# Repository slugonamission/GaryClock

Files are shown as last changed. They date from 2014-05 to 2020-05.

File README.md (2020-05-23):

Time Containment and Dispersal Unit
=========
The structure of this repository is as follows:

* acrylic: Contains the Adobe Illustrator files for the plastic housing, and a template for the scales
* doc: Contains the (incomplete and abandoned) manual.
* libraries: Ignored
* notes: Misc stuff. Contains the programmer <-> clock I2C protocol.
* schematics: Contains the schematic for the power conditioning unit.
* src: Contains the actual clock source and tests.

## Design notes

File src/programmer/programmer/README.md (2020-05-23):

Building this programmer will require a little extra effort, since we're starting to hit the limits of what will actually fit on the Arduino.

Perform the following before attempting to build this project:

* Disable USB HID and CDC for the Arduino Leonardo. Go into Java/hardware/arduino/cores/arduino/USBDesc.h and comment out `#define CDC_ENABLED` and `#define HID_ENABLED`
* The SD card library needs replacing in order to use software SPI. Remove (or rename) Java/libraries/SD and instead use the AdaFruit version from https://learn.adafruit.com/adafruit-micro-sd-breakout-board-card-tutorial/library
* Since CDC is disabled, the Arduino can no longer be reset by the PC. Hit reset on the Arduino for the serial port to be detectable, and reset before attempting to program (the L LED should be pulsing in this period). The Arduino requires a power cycle to boot
        * Even with the HID and CDC libs, it needed power cycling anyway to detect the SD card again for some reason.

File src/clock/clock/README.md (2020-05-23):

Date/DS1307RTC modules taken from http://www.pjrc.com/teensy/td_libs_Time.html and http://www.pjrc.com/teensy/td_libs_DS1307RTC.html.

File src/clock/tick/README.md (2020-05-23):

Testing damping on the voltmeter, stopping some of the intertia from the heavy needle.

Damping is achieved by applying a reverse voltage (proportional to the distance) for a brief period of time after a specified delay from initial movement (the function in the file is fairly self-explanatory).
These values (in the file as #defines) can be tuned to improve the effect (may have to change them if we trim down the needle).

'tick.ino' contains the damped needle move function, as well as tests.

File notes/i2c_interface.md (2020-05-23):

Gary Clock I2C Semantics
==========================
+ The programmer will connect over I2C as a *slave* device.
    + The clock will already be an I2C master to communicate with the RTC.
+ The programmer will have slave ID `0x28`.
+ On connection, the clock must send a transaction to set the current time to the programmer. The programmer *probably* will not start unless this is sent.
+ The transaction format is `<regnum><data1><data2>...<datan>`. Writes to different registers **must** be contained in seperate transactions. Transaction splitting is not supported.
+ The register file is as follows:

        RegNum         Dir          Data
        0              R/W          The current time of the format <hour><min><second>, all as seperate 8 bit words.
        1              R/W          The current LED state.

+ Current I2C layout map:

        Addr          Usage
        0x28          Programmer
        0x68          RTC (DS1338)
        0x70 - 0x72   7-seg displays

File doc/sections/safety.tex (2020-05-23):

%!TEX root=../manual.tex

\begin{figure}[h!]
\centering
To avoid injury, read all operating instructions and the following safety information before using your \touchmore{}. For detailed operating instructions, read this User Guide carefully.
\caption{Important Information Warning 1}
\end{figure}

\begin{figure}[h!]
\centering
Failure to follow these safety instructions could result in fire, electric shock, or other injury or damage to the \touchmore{} or other property.
\caption{Important Information Warning 2}
\end{figure}

\begin{figure}[h!]
\centering
Do not open the \touchmore{} power conditioning unit. This device contains an anti-tamper mechanism which will be triggered by attempting to open the unit. The partners take no responsibility for any damage to persons, property or pride by by attmpting to open this unit.
\caption{Important Information Warning 3}
\end{figure}

\begin{figure}[h!]
\centering
DO NOT CONNECT THE \touchmore{} POWER CONDITIONING UNIT TO MAINS. CONNECTING THE \touchmore{} POWER CONDITIONING UNIT TO MAINS MAY LEAD TO INJURY OR DEATH FOR THE OPERATOR, OR DAMAGE TO ANY CONNECTED COMPONENTS.
\caption{Actual Important Information Warning 1}
\end{figure}

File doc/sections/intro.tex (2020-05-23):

%!TEX root=../manual.tex

Congratulations on the purchase of your new \touchmore{}. If suitably cared for, your \touchmore{} will provide you with years of time viewing pleasure, upon years of time storage.

We here at the Real Time group have used our years of experience in manufacturing, programming, and time viewing in order to create a fantastic timepiece, utilising the most cutting edge research in time viewing, time setting and power conditioning in order to provide you with the best experience possible in the coming \st{millennia} \st{centuries} \st{decades} \st{years} \st{months} days of time viewing that your brand new timepiece is designed for. As the result of the cumilation of three years and two extensions of real-time research, tentatively funded by EU grant number FP7-ICT-2011-7, we are sure that your new timepiece will bring you many minutes of joy.

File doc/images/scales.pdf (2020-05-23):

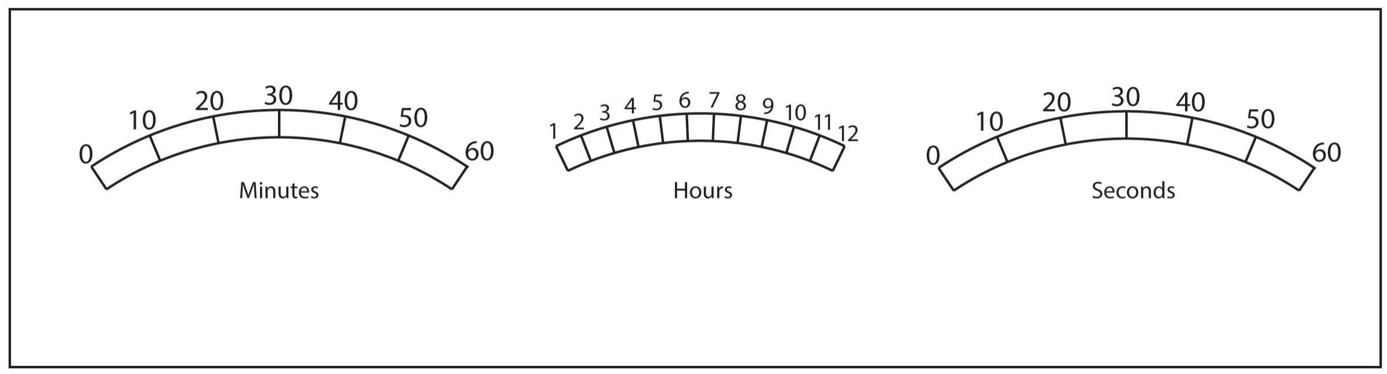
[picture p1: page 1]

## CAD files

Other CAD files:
acrylic/design-landscape.dwg

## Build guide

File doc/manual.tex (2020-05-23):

\documentclass[11pt,a4paper,twoside,titlepage]{scrartcl}

\usepackage[%
  includeheadfoot,
  headheight=44pt,
  headsep=60pt,
  hmargin=2cm,
  top=1cm,
  bottom=1.4cm
]{geometry}
\usepackage[pagestyles,raggedright]{titlesec}
\usepackage{lastpage,multirow,tabularx}
\usepackage{graphicx}
\usepackage{appendix}
\usepackage{lipsum}
\usepackage[pdfusetitle,hidelinks]{hyperref}
\usepackage{listings}
\usepackage{hyperref}
\usepackage{todonotes}
\usepackage{xcolor}
\usepackage{soul}

\usepackage{float}
\restylefloat{table}

\usepackage{datetime}
\ddmmyyyydate

\interfootnotelinepenalty=9999

\lstset{ %
basicstyle=\footnotesize,       % the size of the fonts that are used for the code
numbers=left,                   % where to put the line-numbers
numberstyle=\footnotesize,      % the size of the fonts that are used for the line-numbers
stepnumber=1,                   % the step between two line-numbers. If it's 1 each line will be numbered
numbersep=5pt,                  % how far the line-numbers are from the code
showspaces=false,               % show spaces adding particular underscores
showstringspaces=false,         % underline spaces within strings
showtabs=false,                 % show tabs within strings adding particular underscores
frame=single,                   % adds a frame around the code (tb for top bottom)
tabsize=4,                      % sets default tabsize to 2 spaces
captionpos=b,                   % sets the caption-position to bottom
breaklines=true,                % sets automatic line breaking
breakatwhitespace=false,        % sets if automatic breaks should only happen at whitespace
escapeinside={\%*}{*)}          % if you want to add a comment within your code
}

\title{\vspace{-24pt}\Huge Multi-Function Analogue Clock}
\subtitle{\vspace{8pt}\LARGE User Manual}
\author{}
\date{\vspace{12pt}}

\renewcommand{\tablename}{\textbf{Tip}}
\renewcommand{\figurename}{\textbf{Warning}}
\newcommand{\touchmore}{\textcolor{blue}{ToucHMore Time Storage and Dispersal Unit}}

\newcommand{\clock}{MULTI-FUNCTION~ANALOGUE~CLOCK}

\makeatletter
\let\Title\@title
\let\Author\@author
\let\Date\@date
\makeatother

% Page setup (titlesec)
\newpagestyle{manual}{%
%  \widenhead[1cm][1cm][1cm][1cm]
  \widenhead*{1cm}{1cm}
  \sethead[][\begin{tabularx}{\linewidth}{|>{\centering}p{4cm}|>{\centering}X|p{4cm}|}\hline
               & & \multirow{6}{*}{} \\
               User Manual & \textbf{\MakeUppercase{MULTI-FUNCTION ANALOGUE CLOCK}} & \\
               & & \\ \cline{1-2}
               & & \\
               Page \thepage\ of \pageref{LastPage} & Department of Computer Science, University of York & \\
               & & \\ \hline
             \end{tabularx}][]
          {}{\begin{tabularx}{\linewidth}{|p{4cm}|>{\centering}X|>{\centering\arraybackslash}p{4cm}|}\hline
               \multirow{6}{*}{} & & \\
               & \textbf{\MakeUppercase{MULTI-FUNCTION ANALOGUE CLOCK}} & User Manual \\
               & & \\ \cline{2-3}
               & & \\
               & Department of Computer Science, University of York & Page \thepage\ of \pageref{LastPage} \\
               & & \\ \hline
             \end{tabularx}}{}
  \setfoot[][\begin{tabularx}{\linewidth}{|p{3cm}|p{3cm}|X|}\hline
               Edition: 1 & Revision: A & \multirow{2}{*}{Approved: \textit{RJ, MF, IG, GL, JG}} \\
               Date: \today & Date: \today & \\\hline
             \end{tabularx}][]
          {}{\begin{tabularx}{\linewidth}{|p{3cm}|p{3cm}|X|}\hline
               Edition: 1 & Revision: A & \multirow{2}{*}{Approved: \textit{RJ, MF, IG, GL, JG}} \\
               Date: \today & Date: \today & \\\hline
             \end{tabularx}}{}
}
\pagestyle{manual}

\begin{document}

\maketitle

\section{Introduction}
\input{sections/intro.tex}

\clearpage
\section{Important Safety Information}
\input{sections/safety.tex}

\clearpage
\section{Basic Operation}
\input{sections/basic.tex}

\clearpage
\section{Advanced Functionality}
\input{sections/advanced.tex}

\clearpage
\appendix
\appendixpage

\input{sections/appendices.tex}

\clearpage
\section{Notes}
\vspace{1cm}
\noindent\rule{\textwidth}{0.2pt}
\vspace{1cm}
\noindent\rule{\textwidth}{0.2pt}
\vspace{1cm}
\noindent\rule{\textwidth}{0.2pt}
\vspace{1cm}
\noindent\rule{\textwidth}{0.2pt}
\vspace{1cm}
\noindent\rule{\textwidth}{0.2pt}
\vspace{1cm}
\noindent\rule{\textwidth}{0.2pt}
\vspace{1cm}
\noindent\rule{\textwidth}{0.2pt}
\vspace{1cm}
\noindent\rule{\textwidth}{0.2pt}
\vspace{1cm}
\noindent\rule{\textwidth}{0.2pt}
\vspace{1cm}
\noindent\rule{\textwidth}{0.2pt}
\vspace{1cm}
\noindent\rule{\textwidth}{0.2pt}
\vspace{1cm}
\noindent\rule{\textwidth}{0.2pt}
\vspace{1cm}
\noindent\rule{\textwidth}{0.2pt}
\vspace{1cm}

\clearpage
\section{More Notes}
\vspace{1cm}
\noindent\rule{\textwidth}{0.2pt}
\vspace{1cm}
\noindent\rule{\textwidth}{0.2pt}
\vspace{1cm}
\noindent\rule{\textwidth}{0.2pt}
\vspace{1cm}
\noindent\rule{\textwidth}{0.2pt}
\vspace{1cm}
\noindent\rule{\textwidth}{0.2pt}
\vspace{1cm}
\noindent\rule{\textwidth}{0.2pt}
\vspace{1cm}
\noindent\rule{\textwidth}{0.2pt}
\vspace{1cm}
\noindent\rule{\textwidth}{0.2pt}
\vspace{1cm}
\noindent\rule{\textwidth}{0.2pt}
\vspace{1cm}
\noindent\rule{\textwidth}{0.2pt}
\vspace{1cm}
\noindent\rule{\textwidth}{0.2pt}
\vspace{1cm}
\noindent\rule{\textwidth}{0.2pt}
\vspace{1cm}
\noindent\rule{\textwidth}{0.2pt}
\vspace{1cm}

\end{document}

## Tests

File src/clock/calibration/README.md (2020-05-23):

Used to calibrate the voltmeters through a serial connection.

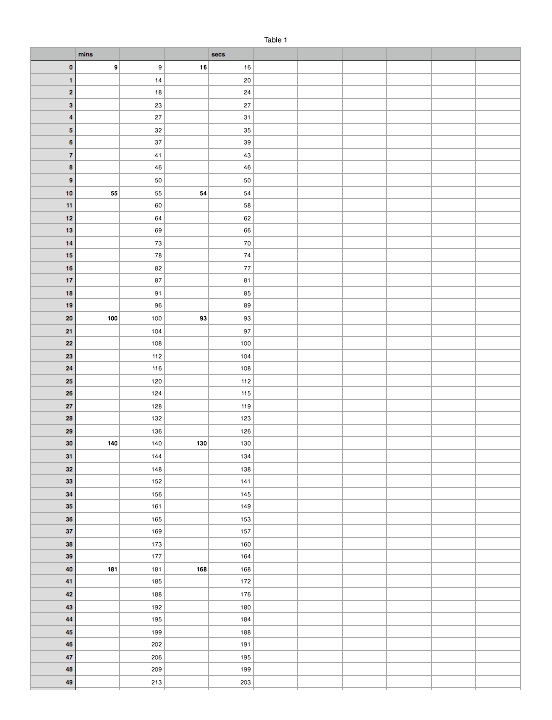
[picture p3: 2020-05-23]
notes/Calibration.numbers/preview.jpg

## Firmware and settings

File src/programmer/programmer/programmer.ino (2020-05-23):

#include <SPI.h>
#include <SD.h>
#include <Wire.h>
#include "Adafruit_GFX.h"
#include "Adafruit_ST7735.h"

// REMOVE THIS BEFORE GIVING TO GARY
//#define SKIP_SHIT

// TFT pins
#define TFT_CS 10
#define TFT_DC 8
#define TFT_RST NULL
#define TFT_MOSI 11
#define TFT_MISO 12
#define TFT_CLK 13
#define TFT_BACKLIGHT 9

// TFT default colours
#define TEXTCOL ST7735_WHITE     // Standard text colour
#define TEXTBG  ST7735_BLACK     // Standard text BG
#define SELTEXTCOL ST7735_BLACK  // Selected text colour
#define SELTEXTBG  ST7735_YELLOW // Selected text background

// SD special pins
#define SD_CS 4

// I2C address in 7-bit format
#define I2C_ADDR 0x28
#define I2CPTR_TIME 0
#define I2CPTR_LEDS 1
#define I2CPTR_STOPWORLD 2
#define I2CPTR_NEUTRINO 3

// I2C vars
uint8_t i2c_regptr = 0;

// Because Adafruit don't actually say the font dimensions, and instead
// just scatter magic bloody numbers everywhere...
#define FONT_WIDTH 6
#define FONT_HEIGHT 8

// Do we have an SD card or not?
int sd_card = 0;

// Startup sequence
char* stringTab[] = {
  "Initialising runtime",
  "Opening SD...",
  "Finding graphic",
  "Reticulating splines",
  "Touch More!",
  NULL
};

#define SDLINE 1
#define GRAPHICLINE 4

// Menu stuff
char* menuTab[] = {
  "Set Time",
  "Set LEDs",
  "Set Brightness",
  "Flappy Plumbridge",
  "Credits",
  "Quiz",
  NULL
};

int selectedItem = 0;

// Page config
int curPage = 0;
#define PAGE_MENU 0
#define PAGE_TIME 1
#define PAGE_LEDS 2
#define PAGE_BRIGHTNESS 3
#define PAGE_FLAPPY 4
#define PAGE_CREDITS 5
#define PAGE_QUIZ 6
#define PAGE_UNDEFINED 255

// Joystick
char keydown = 0;
#define JOY_NONE 0
#define JOY_UP 1
#define JOY_LEFT 2
#define JOY_RIGHT 3
#define JOY_DOWN 4
#define JOY_PRESS 5
char getJoyDir();

// Forward method decls.
void writeOK();
void writeFail();
void drawPBM(char* filename, const int width, const int height, const int xOff, const int yOff);

// Menu page
void printMenuHeader();
void printMenu();
void loopMenu();

// ----------------------------------------
// Time page
#define TIMESEG_HOUR 0
#define TIMESEG_MIN 1
#define TIMESEG_SEC 2
#define TIMESEG_BACK 3

void printTimeHeader();
void printTime();
void reprintTimeSegment(unsigned char selectedSegment);
void loopTime();
uint8_t timeSelectedSegment = TIMESEG_HOUR;
uint8_t timeCurrent[3] = {0, 0, 0};

// -----------------------------------------
// LED Mode page
void printLEDHeader();
void printLED();
void loopLED();
unsigned char ledMode = 1;
uint16_t ledColours[] = {
  ST7735_BLUE,
  ST7735_CYAN,
  ST7735_MAGENTA,
  ST7735_YELLOW,
  ST7735_RED
};

// -----------------------------------------
// Brightness page
void printBrightnessHeader();
void loopBrightness();
unsigned char curBrightness = 255;

// -----------------------------------------
// Flappy Plumbridge
void printFlappyHeader();
void loopFlappy();
int barHeights[5] = {50, 50, 50, 50, 50};
int firstBarIdx = 0;
int leadingBarSize = 0;
int flapHeight = 0;

// -----------------------------------------
// Credits page
void printCreditsHeader();
void loopCredits();
uint8_t creditsIdx = 0;

// -----------------------------------------
// Quiz page
void printQuizHeader();
void printQuestion();
void loopQuiz();
void selectAnswer(int ans);
void checkAnswer();
int questionNo = 0;
int selectedAnswer = 0;
int correctAnswer = 0;

File questionFile;
bool questionFileOpen = false;

#define QUIZANS_TOP 70

// -----------------------------------------
// Undefined page
void printUndefinedHeader();
void loopUndefined();


// The actual screen...
Adafruit_ST7735 tft(TFT_CS, TFT_DC, TFT_MOSI, TFT_CLK, TFT_RST);

// "BUT JAMIE!", I hear you say, "PBM ENCODES THE WIDTH AND HEIGHT YOU NOOB", you go on.
// Well, I can't be fucked. Reading those requires proper string reading routines, proper
// buffers, and conversion routines. We're running out of space already (so much so I'm tempted
// to remove the filetype check), so deal with it.
void drawPBM(char* filename, const int width, const int height, const int xOff, const int yOff)
{
  File f = SD.open(filename, FILE_READ);
  int headerLines = 4;
  int curX = 0;
  int curY = 0;
  int maxPix = width * height;
  
  char buf[3];
  
  if(!f)
    tft.println("Couldn't open file");
  
  // Read the header
  buf[0] = f.read();
  buf[1] = f.read();
  
  if(buf[0] != 'P' || buf[1] != '6')
  {
    tft.println("Unknown file");
    return;
  }
  
  // Read the rest of the header
  while(headerLines)
  {
    if(f.read() == '\n')
      headerLines--;
  }
  
   for(curY = yOff; curY < yOff + height; curY++)
   {
     for(curX = xOff; curX < xOff + width; curX++)
     {
       buf[0] = f.read(); // R
       buf[1] = f.read(); // G
       buf[2] = f.read(); // B
       tft.drawPixel(curX, curY, tft.Color565(buf[0], buf[1], buf[2]));
     }
   }
   
   f.close();
}

void writeOK()
{
  tft.write('[');
  tft.setTextColor(ST7735_GREEN);
  tft.print("OK");
  tft.setTextColor(TEXTCOL);
  tft.write(']');
}

void writeFail()
{
  tft.write('[');
  tft.setTextColor(ST7735_RED);
  tft.print("FAIL");
  tft.setTextColor(TEXTCOL);
  tft.write(']');
}

void i2c_recv(int numBytes)
{
  if(numBytes == 0)
    return;
    
  // Get the reg no
  i2c_regptr = Wire.read();
  numBytes--;
  
  if(numBytes == 0)
    return;
  
  switch(i2c_regptr)
  {
    case I2CPTR_TIME:
      {
        int timePtr = 0;
        while(numBytes && (timePtr != 3))
        {
          timeCurrent[timePtr] = Wire.read();
          numBytes--;
          timePtr++;
        }
      }
      break;
    
    case I2CPTR_LEDS:
      ledMode = Wire.read();
      numBytes--;
      break;
  }
  
  // Blackhole
  while(numBytes--)
    Wire.read();
}

void i2c_trans()
{
  switch(i2c_regptr)
  {
    case I2CPTR_TIME:
      {
        Wire.write(timeCurrent, 3);
      }
      break;
    
    case I2CPTR_LEDS:
      Wire.write(ledMode);
      break;
    case I2CPTR_STOPWORLD:
      if(curPage == PAGE_TIME)
        Wire.write((uint8_t)1);
      else
        Wire.write((uint8_t)0);
      break;
    case I2CPTR_NEUTRINO:
      if(curPage == PAGE_UNDEFINED)
        Wire.write((uint8_t)1);
      else
        Wire.write((uint8_t)0);
      break;
  }
}

void setup()
{
  pinMode(TFT_BACKLIGHT, OUTPUT);
  pinMode(SD_CS, OUTPUT);
  analogWrite(TFT_BACKLIGHT, 255);
  
  tft.initR(INITR_BLACKTAB);
  #ifndef SKIP_SHIT
  tft.fillScreen(ST7735_MAGENTA);
  tft.fillScreen(ST7735_CYAN);
  tft.fillScreen(ST7735_YELLOW);
  tft.fillScreen(ST7735_WHITE);
  tft.fillScreen(ST7735_RED);
  tft.fillScreen(ST7735_GREEN);
  tft.fillScreen(ST7735_BLUE);
  #endif
  tft.fillScreen(TEXTBG);
  tft.setRotation(3);
  
  Wire.begin(I2C_ADDR);
  Wire.onReceive(i2c_recv);
  Wire.onRequest(i2c_trans);
  
  randomSeed(analogRead(1));
  
  // Init SD card...
  // Check for SD Card
  if (!SD.begin(SD_CS, TFT_MOSI, TFT_MISO, TFT_CLK)) 
  {
    // No SD card, or failed to initialise card
    sd_card=0;
    // Arduino SD library does something to SPI speed when it fails
    // So need to reset otherwise screen is slow.
    SPI.setClockDivider(SPI_CLOCK_DIV4); // 16/4 MHz
  }  
  else sd_card=1;
  
  int curStrIdx = 0;
  
#ifndef SKIP_SHIT
  while(stringTab[curStrIdx] != 0)
  {
    tft.setCursor(0, curStrIdx * FONT_HEIGHT);
    tft.print(stringTab[curStrIdx]);

    tft.setCursor(160 - (4*FONT_WIDTH), curStrIdx * FONT_HEIGHT);    
    
    if(curStrIdx == SDLINE)
    {
      if(!sd_card)
      {
        tft.setCursor(160 - (6*FONT_WIDTH), curStrIdx*FONT_HEIGHT);
        writeFail();
        tft.println();
        tft.print("!!! \"KERNEL\" PANIC !!!");
        while(1)
        {
          tft.invertDisplay(sd_card);
          sd_card = (sd_card + 1) % 2;
          delay(500);
        }
      }
    }
    
    if(curStrIdx != GRAPHICLINE)
      writeOK();
    else
    {
      tft.setCursor(160 - (6*FONT_WIDTH), curStrIdx*FONT_HEIGHT);
      writeFail();
    }
    
    if(curStrIdx == GRAPHICLINE)
    {
      drawPBM("touch.pbm", 80, 40, 40, 68);
    }
    
    delay(2000);
    curStrIdx++;
  }
  
  for(int i = 255; i >= 0; i--)
  {
    analogWrite(TFT_BACKLIGHT, i);
    delay(6);
  }
  
  for(int i = 0; i < 256; i++)
  {
    analogWrite(TFT_BACKLIGHT, i);
    delay(6);
  }
  
  for(int i = 1; i < 9; i++)
  {
    tft.invertDisplay(i % 2);
    delay(200);
  }
  
  delay(5000);
#endif
  printMenuHeader();
  printMenu();
}

char getJoyDir()
{
  int x;
  
  x = analogRead (0);               // Read Jog switch input
  
  if ((x < 100) & (keydown==0)) {
    // Select
    keydown=1;
    return JOY_PRESS;
  }
  else if ((x < 200) & (keydown==0)) {
    // Up
    keydown=1;
    return JOY_UP;
  }
  else if ((x < 400) & (keydown==0)){
    // Left
    keydown=1;
    return JOY_LEFT;    
  }
  else if ((x < 600) & (keydown==0)){
    // Down
    keydown=1;
    return JOY_DOWN;
  }
  else if ((x < 800) & (keydown==0)){
    // Right
    keydown=1;    
    return JOY_RIGHT;
  }  
  else if (x >= 800)
  {
    keydown=0; // key released
  }
  
  return JOY_NONE;
}

void loop()
{
  if(curPage == PAGE_MENU)
    loopMenu();
  if(curPage == PAGE_LEDS)
    loopLED();
  if(curPage == PAGE_TIME)
    loopTime();
  if(curPage == PAGE_BRIGHTNESS)
    loopBrightness();
  if(curPage == PAGE_FLAPPY)
    loopFlappy();
  if(curPage == PAGE_CREDITS)
    loopCredits();
  if(curPage == PAGE_QUIZ)
    loopQuiz();
  if(curPage == PAGE_UNDEFINED)
    loopUndefined();
}

// --------------------------------------------------
void printMenuHeader()
{
  tft.fillScreen(ST7735_BLACK);
  
  tft.setCursor(30, 0);
  tft.println("ToucHMore Remote");
  tft.drawFastHLine(0, 10, 160, SELTEXTBG);
  tft.setCursor(0, 15);
}

void selectItem(int item)
{
  // Highlight new one...
  tft.setCursor(0, 15 + (FONT_HEIGHT * item));
  tft.setTextColor(SELTEXTCOL, SELTEXTBG);
  tft.print(menuTab[item]);
  
  // Blank the previous item
  tft.setCursor(0, 15 + (FONT_HEIGHT * selectedItem));
  tft.setTextColor(TEXTCOL, TEXTBG);
  tft.print(menuTab[selectedItem]);
  
  selectedItem = item;
}

void printMenu()
{
  int menuIndex = 0;
  tft.setCursor(0, 15);
  
  tft.setTextColor(TEXTCOL);
  
  while(menuTab[menuIndex] != 0)
  {
    if(menuIndex == selectedItem)
      tft.setTextColor(SELTEXTCOL, SELTEXTBG);
    else
      tft.setTextColor(TEXTCOL);
    tft.println(menuTab[menuIndex++]);
  }
}

void loopMenu()
{
  char dir = getJoyDir();
  if(dir == JOY_DOWN)
    selectItem(selectedItem + 1);
  else if(dir == JOY_UP)
    selectItem(selectedItem - 1);
  else if(dir == JOY_PRESS)
  {
    switch(selectedItem)
    {
      case 0:
        printTimeHeader();
        curPage = PAGE_TIME;
        break;
       
      case 1:
        printLEDHeader();
        curPage = PAGE_LEDS;
        break;
        
      case 2:
       printBrightnessHeader();
       curPage = PAGE_BRIGHTNESS;
       break;
       
     case 3:
       printFlappyHeader();
       curPage = PAGE_FLAPPY;
       break;
       
     case 4:
       printCreditsHeader();
       curPage = PAGE_CREDITS;
       break;
       
     case 5:
       printQuizHeader();
       curPage = PAGE_QUIZ;
       break;
       
     default:
       curPage = PAGE_UNDEFINED;
       printUndefinedHeader();
       break;
    }
  }
}

// -------------------------------------------------

void printTimeHeader()
{
  tft.fillScreen(ST7735_BLACK);
  
  tft.setCursor(50, 0);
  tft.println("Time Config");
  tft.drawFastHLine(0, 10, 160, SELTEXTBG);
  tft.setCursor(0, 15);
  
  printTime();
}

void reprintTimeSegment(unsigned char selectedSegment)
{
  if(selectedSegment > 2)
    return;
    
  tft.setTextColor(SELTEXTCOL, SELTEXTBG);
  tft.setTextSize(3);
  
  tft.setCursor(5 + (selectedSegment * 3 * FONT_WIDTH) + (selectedSegment * 3 * 2 * FONT_WIDTH), 30);
  if(timeCurrent[selectedSegment] < 10)
    tft.write('0');
  tft.print(timeCurrent[selectedSegment]);
  
  tft.setTextColor(TEXTCOL);
  tft.setTextSize(1);
}

// TODO: This needs optimising with the larger font...
void printTime()
{
  tft.setCursor(5, 30);
  tft.setTextSize(3);
  tft.setTextColor(TEXTCOL, TEXTBG);
  
  // Hours...
  if(timeSelectedSegment == TIMESEG_HOUR)
    tft.setTextColor(SELTEXTCOL, SELTEXTBG);
  if(timeCurrent[0] < 10)
    tft.write('0');
  tft.print(timeCurrent[0]);
  
  tft.setTextColor(TEXTCOL, TEXTBG);
  tft.write(':');
  
  // Minutes...
  if(timeSelectedSegment == TIMESEG_MIN)
    tft.setTextColor(SELTEXTCOL, SELTEXTBG);
  if(timeCurrent[1] < 10)
    tft.write('0');
  tft.print(timeCurrent[1]);
  
  tft.setTextColor(TEXTCOL, TEXTBG);
  tft.write(':');
  
  // Seconds...
  if(timeSelectedSegment == TIMESEG_SEC)
    tft.setTextColor(SELTEXTCOL, SELTEXTBG);
  if(timeCurrent[2] < 10)
    tft.write('0');
  tft.print(timeCurrent[2]);
  
  tft.setTextColor(TEXTCOL, TEXTBG);
  
  tft.setCursor(55, 60);
  tft.setTextSize(1);
  
  if(timeSelectedSegment == TIMESEG_BACK)
    tft.setTextColor(SELTEXTCOL, SELTEXTBG);
  tft.print("<<< Back");
  tft.setTextColor(TEXTCOL);
}

void loopTime()
{
  char dir = getJoyDir();
  
  if(dir == JOY_LEFT)
  {
    timeSelectedSegment--;
    printTime();
  }
  
  if(dir == JOY_RIGHT)
  {
    timeSelectedSegment++;
    printTime();
  }
  
  if(dir == JOY_UP && timeSelectedSegment <= TIMESEG_SEC)
  {
    if(timeSelectedSegment == TIMESEG_HOUR && timeCurrent[timeSelectedSegment] == 23)
      timeCurrent[timeSelectedSegment] = 0;
    else if(timeCurrent[timeSelectedSegment] == 59)
      timeCurrent[timeSelectedSegment] = 0;
    else
      timeCurrent[timeSelectedSegment]++;
    reprintTimeSegment(timeSelectedSegment);
    //printTime();
  }
  
  if(dir == JOY_DOWN && timeSelectedSegment <= TIMESEG_SEC)
  {
    if(timeCurrent[timeSelectedSegment] == 0)
    {
      if(timeSelectedSegment == TIMESEG_HOUR)
        timeCurrent[timeSelectedSegment] = 23;
      else
        timeCurrent[timeSelectedSegment] = 59;
    }
    else
      timeCurrent[timeSelectedSegment]--;
    reprintTimeSegment(timeSelectedSegment);
    //printTime();
  }
  
  if(dir == JOY_PRESS && timeSelectedSegment == TIMESEG_BACK)
  {
    curPage = PAGE_MENU;
    printMenuHeader();
    printMenu();
  }
}

// -------------------------------------------------

void printLEDHeader()
{
  tft.fillScreen(ST7735_BLACK);
  
  tft.setCursor(50, 0);
  tft.println("LED Config");
  tft.drawFastHLine(0, 10, 160, SELTEXTBG);
  tft.setCursor(0, 15);
  
  printLED();
}

void printLED()
{
  tft.setTextSize(12);
  tft.setTextColor(ledColours[ledMode%5], ST7735_BLACK);
  tft.setCursor(50, 15);
  
  tft.print(ledMode);
  tft.setTextSize(1);
  tft.setTextColor(ST7735_WHITE);
}

void loopLED()
{
  char dir = getJoyDir();
  if(dir == JOY_UP)
  {
    ledMode--;
    printLED();
  }
  else if(dir == JOY_DOWN)
  {
    ledMode++;
    printLED();
  }
  else if(dir == JOY_LEFT)
  {
    curPage = PAGE_MENU;
    printMenuHeader();
    printMenu();
  }
}

// -------------------------------------------------

void printBrightnessHeader()
{
  tft.fillScreen(TEXTBG);
  
  tft.setCursor(50, 0);
  tft.println("Brightness");
  tft.drawFastHLine(0, 10, 160, SELTEXTBG);
  tft.setCursor(50, 15);
  tft.setTextSize(3);
    if(curBrightness < 100)
      tft.print('0');
    if(curBrightness < 10)
      tft.print('0');
    tft.print(curBrightness);
    tft.setTextSize(1);
}

void loopBrightness()
{
  char dir = getJoyDir();
  if(dir == JOY_UP)
  {
    curBrightness += 5;
    analogWrite(TFT_BACKLIGHT, curBrightness);
    tft.setCursor(50, 15);
    tft.setTextSize(3);
    if(curBrightness < 100)
      tft.print('0');
    if(curBrightness < 10)
      tft.print('0');
    tft.print(curBrightness);
    tft.setTextSize(1);
  }
  else if(dir == JOY_DOWN)
  {
    curBrightness -= 5;
    analogWrite(TFT_BACKLIGHT, curBrightness);
    tft.setCursor(50, 15);
    tft.setTextSize(3);
    if(curBrightness < 100)
      tft.print('0');
    if(curBrightness < 10)
      tft.print('0');
    tft.print(curBrightness);
    tft.setTextSize(1);
  }
  else if(dir == JOY_LEFT)
  {
    curPage = PAGE_MENU;
    printMenuHeader();
    printMenu();
  }
}

// -------------------------------------------------------
void printFlappyHeader()
{
  firstBarIdx = 0;
  barHeights[0] = 50; // Mmm...unrolling...
  barHeights[1] = 50;
  barHeights[2] = 50;
  barHeights[3] = 50;
  barHeights[4] = 50;
  leadingBarSize = 10;
  
  flapHeight = 60;
  
  int i = 0;
  int bar = firstBarIdx;
  tft.fillScreen(TEXTBG);
  
  tft.setCursor(35, 0);
  tft.println("Flappy Plumbridge");
  tft.drawFastHLine(0, 10, 160, SELTEXTBG);
  
  // Draw the initial bars...
  for(i = 0; i < 5; i++)
  {
    tft.fillRect(leadingBarSize + (i*30), 15, 10, barHeights[bar], ST7735_GREEN);
    tft.fillRect(leadingBarSize + (i*30), 15 + barHeights[bar] + 30, 10, 145 - (15 + barHeights[bar] + 30), ST7735_CYAN);
    bar = (bar + 1) % 5;
  }
  
  //tft.fillRect(15, 15, 10, 50, ST7735_GREEN);
  //tft.fillRect(15, 85, 10, 43, ST7735_CYAN);
  
  //tft.setCursor(15, 65);
  //tft.println("NOT IMPLEMENTED YET");
}

void loopFlappy()
{
  // Shave 1px off the tail of each bar, and add one to the head of each bar.
  // Shave cycle
  char dir = getJoyDir();
  
  int i = 0;
  int bar = firstBarIdx;
  
  for(i = 0; i < 5; i++)
  {
    tft.drawFastVLine(leadingBarSize + (i*30) + 10, 15, barHeights[bar], ST7735_BLACK);
    tft.drawFastVLine(leadingBarSize + (i*30) + 10, 15 + barHeights[bar] + 30, 145 - (15 + barHeights[bar] + 30), ST7735_BLACK);
    bar = (bar + 1) % 5;
  }
  
  for(i = 0; i < 5; i++)
  {
    if(leadingBarSize > 0 || i != 0)
    {
      tft.drawFastVLine(leadingBarSize + (i*30) - 1, 15, barHeights[bar], ST7735_GREEN);
      tft.drawFastVLine(leadingBarSize + (i*30) - 1, 15 + barHeights[bar] + 30, 145 - (15 + barHeights[bar] + 30), ST7735_CYAN);
    }
    bar = (bar + 1) % 5;
  }  
  
  leadingBarSize--;
  if(leadingBarSize == -11)
  {
    leadingBarSize = 19;
    firstBarIdx = (firstBarIdx + 1) % 5;
    
    // Gen the new bar...
    int nextBar = (firstBarIdx + 4) % 5;
    barHeights[nextBar] = random(5, 80);
  }
  
  // Move the flap
  tft.fillRect(5, flapHeight, 5, 5, ST7735_BLACK);
  
  // Trajectory smoothing? Hah.
  if(dir == JOY_PRESS && flapHeight >= 0)
    flapHeight -= 10;
  else if(flapHeight < 115)
    flapHeight += 2;
  
  tft.fillRect(5, flapHeight, 5, 5, ST7735_RED);
  
  if(dir == JOY_LEFT)
  {
    curPage = PAGE_MENU;
    printMenuHeader();
    printMenu();
  }
}

// -------------------------------------------------------
void printCreditsHeader()
{
  // Done in loop()...
  //tft.fillScreen(TEXTBG);
  creditsIdx = 0;
  //drawPBM("neil.pbm", 160, 107, 0, 10);
}

void loopCredits()
{
  char dir = getJoyDir();
  tft.fillScreen(TEXTBG);
  switch(creditsIdx++)
  {
    case 0:
      drawPBM("neil.pbm", 160, 107, 0, 10);
      break;
    case 1:
      drawPBM("cat.pbm", 160, 107, 0, 10);
      break;
    case 2:
      drawPBM("gary.pbm", 160, 107, 0, 10);
      break;
    case 3:
      drawPBM("xilinx.pbm", 160, 47, 0, 40);
      break;
    case 4:
      drawPBM("fp7.pbm", 104, 128, 28, 0);
      break;
    case 5:
      drawPBM("gary1.pbm", 156, 128, 2, 0);
      break;
    case 6:
      drawPBM("gary2.pbm", 136, 128, 12, 0);
      break;
    case 7:
      drawPBM("gary3.pbm", 133, 128, 13, 0);
      break;
    case 8:
      drawPBM("gary4.pbm", 137, 128, 12, 0);
      break;
  }  
  
  if(creditsIdx > 8)
    creditsIdx = 0;
  
  if(dir == JOY_LEFT)
  {
    curPage = PAGE_MENU;
    printMenuHeader();
    printMenu();
  }
}

// -------------------------------------------------------
void printQuizHeader()
{
  tft.fillScreen(TEXTBG);
  
  tft.setCursor(60, 0);
  tft.println("Quiz!");
  tft.drawFastHLine(0, 10, 160, SELTEXTBG);
  printQuestion();
}

void printQuestion()
{
  char c;
  int readA = 0;
  
  tft.setCursor(0, 16);
  
  if(!questionFileOpen)
  {
    questionFile = SD.open("quiz.txt", FILE_READ);
    if(!questionFile)
    {
      tft.println("Could not open quiz.txt");
      return;
    }
    questionFileOpen = true;
  }
 
  while((c = questionFile.read()) != '\n')
    tft.print(c);
    
  tft.setCursor(0, QUIZANS_TOP);
  tft.print("  ");
  
  while(readA != 4)
  {
    c = questionFile.read();
    if(c == '*')
    {
      correctAnswer = readA;
      continue;
    }
    
    if(c == '\n')
    {
      tft.print("\n  ");
      readA++;
      continue;
    }
    
    tft.print(c);
  }
  
  selectAnswer(0);
}

void selectAnswer(int ans)
{
  tft.setTextColor(ST7735_WHITE, ST7735_BLACK);
  tft.setCursor(0, QUIZANS_TOP + (FONT_HEIGHT*selectedAnswer));
  tft.print("  ");
  tft.setCursor(0, QUIZANS_TOP + (FONT_HEIGHT*ans));
  tft.print("->");
  tft.setTextColor(ST7735_WHITE);
  
  selectedAnswer = ans;
}

void checkAnswer()
{
  tft.setCursor(40, 120);
  if(selectedAnswer == correctAnswer)
  {
    tft.setTextColor(ST7735_BLACK, ST7735_GREEN);
    tft.print("CORRECT");
  }
  else
  {
    tft.setTextColor(ST7735_BLACK, ST7735_RED);
    tft.print("WRONG");
    tft.setCursor(0, QUIZANS_TOP + (FONT_HEIGHT*correctAnswer));
    tft.print("->");
  }
  tft.setTextColor(ST7735_WHITE);
  
  delay(5000);
  printQuizHeader();
}

void loopQuiz()
{
  char dir = getJoyDir();
  if(dir == JOY_LEFT)
  {
    questionFile.close();
    questionFileOpen = false;
    curPage = PAGE_MENU;
    printMenuHeader();
    printMenu();
  }
  
  if(dir == JOY_UP)
  {
    selectAnswer(selectedAnswer - 1);
  }
  
  if(dir == JOY_DOWN)
  {
    selectAnswer(selectedAnswer + 1);
  }
  
  if(dir == JOY_PRESS)
  {
    checkAnswer();
  }
}
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

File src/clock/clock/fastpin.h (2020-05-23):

#ifndef __INC_FASTPIN_H
#define __INC_FASTPIN_H

#include<avr/io.h>

// Arduino.h needed for convinience functions digitalPinToPort/BitMask/portOutputRegister and the pinMode methods.
#include<Arduino.h>

#define NO_PIN 255 

// Class to ensure that a minimum amount of time has kicked since the last time run - and delay if not enough time has passed yet
// this should make sure that chipsets that have 
template<int WAIT> class CMinWait {
	long mLastMicros;
public:
	CMinWait() { mLastMicros = 0; }

	void wait() { 
		long diff = micros() - mLastMicros;
		while(diff < WAIT) { 
			diff = micros() - mLastMicros;
		}
	}

	void mark() { mLastMicros = micros(); }
};

//////////////////////////////////////////////////////////////////////////////////////////////////////////////////////////////////
//
// Pin access class - needs to tune for various platforms (naive fallback solution?)
//
//////////////////////////////////////////////////////////////////////////////////////////////////////////////////////////////////

#if defined(__AVR_ATmega1280__) || defined(__AVR_ATmega2560__)
#define _CYCLES(_PIN) (((_PIN >= 62 ) || (_PIN>=42 && _PIN<=49) || (_PIN>=14 && _PIN <=17) || (_PIN>=6 && _PIN <=9)) ? 2 : 1)
#else
#define _CYCLES(_PIN) ((_PIN >= 24) ? 2 : 1)
#endif

class Selectable {
public:
	virtual void select() = 0;
	virtual void release() = 0;
	virtual bool isSelected() = 0;
};

class Pin : public Selectable { 
	uint8_t mPinMask;
	uint8_t mPin;
	volatile uint8_t *mPort;

	void _init() { 
		mPinMask = digitalPinToBitMask(mPin);
		mPort = portOutputRegister(digitalPinToPort(mPin));
	}
public:
	Pin(int pin) : mPin(pin) { _init(); }

	typedef volatile uint8_t * port_ptr_t;
	typedef uint8_t port_t;

	inline void setOutput() { pinMode(mPin, OUTPUT); }
	inline void setInput() { pinMode(mPin, INPUT); }

	inline void hi() __attribute__ ((always_inline)) { *mPort |= mPinMask; } 
	inline void lo() __attribute__ ((always_inline)) { *mPort &= ~mPinMask; }

	inline void strobe() __attribute__ ((always_inline)) { hi(); lo(); }

	inline void hi(register port_ptr_t port) __attribute__ ((always_inline)) { *port |= mPinMask; } 
	inline void lo(register port_ptr_t port) __attribute__ ((always_inline)) { *port &= ~mPinMask; } 
	inline void set(register port_t val) __attribute__ ((always_inline)) { *mPort = val; }

	inline void fastset(register port_ptr_t port, register port_t val) __attribute__ ((always_inline)) { *port  = val; }

	port_t hival() __attribute__ ((always_inline)) { return *mPort | mPinMask;  }
	port_t loval() __attribute__ ((always_inline)) { return *mPort & ~mPinMask; }
	port_ptr_t  port() __attribute__ ((always_inline)) { return mPort; }
	port_t mask() __attribute__ ((always_inline)) { return mPinMask; }

	virtual void select() { hi(); }
	virtual void release() { lo(); }
	virtual bool isSelected() { return (*mPort & mPinMask) == mPinMask; }
};

class OutputPin : public Pin {
public:
	OutputPin(int pin) : Pin(pin) { setOutput(); }
};

class InputPin : public Pin {
public:
	InputPin(int pin) : Pin(pin) { setInput(); }
};

/// The simplest level of Pin class.  This relies on runtime functions durinig initialization to get the port/pin mask for the pin.  Most
/// of the accesses involve references to these static globals that get set up.  This won't be the fastest set of pin operations, but it
/// will provide pin level access on pretty much all arduino environments.  In addition, it includes some methods to help optimize access in
/// various ways.  Namely, the versions of hi, lo, and fastset that take the port register as a passed in register variable (saving a global
/// dereference), since these functions are aggressively inlined, that can help collapse out a lot of extraneous memory loads/dereferences.
/// 
/// In addition, if, while writing a bunch of data to a pin, you know no other pins will be getting written to, you can get/cache a value of
/// the pin's port register and use that to do a full set to the register.  This results in one being able to simply do a store to the register,
/// vs. the load, and/or, and store that would be done normally.
///
/// There are platform specific instantiations of this class that provide direct i/o register access to pins for much higher speed pin twiddling.
///
/// Note that these classes are all static functions.  So the proper usage is Pin<13>::hi(); or such.  Instantiating objects is not recommended, 
/// as passing Pin objects around will likely -not- have the effect you're expecting.
template<uint8_t PIN> class FastPin { 
	static uint8_t sPinMask;
	static volatile uint8_t *sPort;
	static void _init() { 
		sPinMask = digitalPinToBitMask(PIN);
		sPort = portOutputRegister(digitalPinToPort(PIN));
	}
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

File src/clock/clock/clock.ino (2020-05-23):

#include "clock.h"
#include "DS1307RTC.h"
#include "SevenSeg.h"
#include "Voltmeter.h"
#include "Leds.h"
#include "Programmer.h"
#include "animations.h"
#include <EEPROM.h>
#include <Wire.h>

uint8_t curTime[] = {0, 0, 0};

uint8_t meterHoffset[] = {15,37,60,82,104,125,146,164,185,206,227,247};
uint8_t meterMoffset[] = {9,14,18,23,27,32,37,41,46,50,55,60,64,69,73,78,82,87,91,96,100,104,108,112,116,120,124,128,132,136,140,144,148,152,156,161,165,169,173,177,181,185,188,192,195,199,202,206,209,213,216,220,224,227,231,235,239,243,246,250,254};
uint8_t meterSoffset[] = {16,20,24,27,31,35,39,43,46,50,54,58,62,66,70,74,77,81,85,89,93,97,100,104,108,112,115,119,123,126,130,134,138,141,145,149,153,157,160,164,168,172,176,180,184,188,191,195,199,203,207,211,215,218,222,226,230,234,237,241};

// 7-segment displays (left, middle, right)
//SevenSeg segL = SevenSeg();
//SevenSeg segM = SevenSeg();
//SevenSeg segR = SevenSeg();

Voltmeter meterH = Voltmeter();
Voltmeter meterM = Voltmeter();
Voltmeter meterS = Voltmeter();
Voltmeter shitMeters[2];
volatile int metersToUpdate = 0;
uint8_t meterPositions[3];

int hoursSinceNeutrinos;

Leds leds = Leds();

Programmer programmer = Programmer();
bool gotProgrammer = 0;
bool stopWorld = 0;
bool wasCharging = 0;
bool charging = 0;

// This is to allow the programmer loop to be able to skip iterations. This is because if each iteration
// of loop() caused an I2C transaction, the programmer would basically stop due to the number of incoming
// transactions. This then allows loop() to drive the LED patterns and still query the programmer.
#define PROGRAMMER_SKIP_NUM 1
volatile int programmerLoopSkip = 1;

// Forward prototypes
uint8_t make12Hour(uint8_t hour24);
uint8_t makeMeterTime(uint8_t hour24);
void rtcTick();


uint8_t make12Hour(uint8_t hour24)
{
  if(hour24 == 0)
    return 12;
  if(hour24 > 12)
    return hour24 - 12;
  return hour24;
}

uint8_t makeMeterTime(uint8_t hour24)
{
  return make12Hour(hour24) - 1;
}

void rtcTick()
{
	programmerLoopSkip--;
	if(stopWorld)
		return;
	// DO NOT ISSUE AN I2C TRANSACTION IN THIS ISR.
	// WE ISSUE THESE IN loop(). RACE CONDITIONS CAN ARISE.
	// Also, remember that DELAYS DO NOT WORK in ISRs.
	curTime[SECS]++;
	if(curTime[SECS] == 60)
	{
		curTime[SECS] = 0;
		curTime[MINS]++;

		if(curTime[MINS] == 60)
		{
			curTime[MINS] = 0;
			curTime[HOUR]++;

			if(curTime[HOUR] == 23)
				curTime[HOUR] = 0;

			metersToUpdate++;

			meterPositions[HOUR] = meterHoffset[makeMeterTime(curTime[HOUR])];
		}

		metersToUpdate++;
		meterPositions[MINS] = meterMoffset[curTime[MINS]];

		//We just ticked the minute, so we may also need to issue a new animation
		if(leds.getMode() == LEDMODE_SMALL) {
			set_animation(&leds, random(ANIM_SMALL_NUM) + ANIM_SMALL_START, 19);
		}
	}

	//We just ticked the second, so we may also need to issue a new animation
	if(leds.getMode() == LEDMODE_PULSE) {
		if (metersToUpdate == 0)
			set_animation(&leds, ANIM_ID_PULSE, 10);
		else
			set_animation(&leds, ANIM_ID_PULSE, 19);
	}

	metersToUpdate++;
	meterPositions[SECS] = meterSoffset[curTime[SECS]];
}


//Interrupt handler for timer2. Used to tick LED animations.
ISR(TIMER2_COMPA_vect) {
	animation_tick(&leds);
}

void maybeChargeNeutrinos() {
	if (random(NEUTRINOS_PROB) == 0 || hoursSinceNeutrinos > NEUTRINOS_PROB) {
		hoursSinceNeutrinos = 0;
		chargeNeutrinos();
	}
	else {
		hoursSinceNeutrinos++;
	}
}

void chargeNeutrinos() {
	// Disable interrupts
	detachInterrupt(RTC_INT);
	TIMSK2 &= ~(1 << OCIE2A);

	Voltmeter allMeters[] = {meterM, meterS, meterH};
	leds.chargeNeutrinos(allMeters);

	setTimeFromRTC();

	// Re-enable interrupts
	attachInterrupt(RTC_INT, rtcTick, RISING);
	TIMSK2 |= (1 << OCIE2A);
}

void setTimeFromRTC() {
	time_t tz = RTC.get(); 
	curTime[HOUR] = hour(tz);
	curTime[MINS] = minute(tz);
	curTime[SECS] = second(tz);

	// Set the voltmeters
	meterPositions[SECS] = meterSoffset[curTime[SECS]];
	meterPositions[MINS] = meterMoffset[curTime[MINS]];
	meterPositions[HOUR] = meterHoffset[makeMeterTime(curTime[HOUR])];
	meterH.move(meterPositions[HOUR]);
	Voltmeter::moveMultipleDamped(shitMeters, 2, meterPositions);
}
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

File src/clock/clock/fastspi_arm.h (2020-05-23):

#ifndef __INC_FASTSPI_ARM_H
#define __INC_FASTSPI_ARM_H


#if defined(__MK20DX128__) && defined(CORE_TEENSY)

#ifndef SPI_PUSHR_CONT
#define SPI_PUSHR_CONT SPI0_PUSHR_CONT
#define SPI_PUSHR_CTAS(X) SPI0_PUSHR_CTAS(X)
#define SPI_PUSHR_EOQ SPI0_PUSHR_EOQ
#define SPI_PUSHR_CTCNT SPI0_PUSHR_CTCNT
#define SPI_PUSHR_PCS(X) SPI0_PUSHR_PCS(X)
#endif

// Template function that, on compilation, expands to a constant representing the highest bit set in a byte.  Right now, 
// if no bits are set (value is 0), it returns 0, which is also the value returned if the lowest bit is the only bit
// set (the zero-th bit).  Unclear if I  will want this to change at some point.
template<int VAL, int BIT> class BitWork { 
	public: 
		static int highestBit() __attribute__((always_inline)) { return (VAL & 1 << BIT) ? BIT : BitWork<VAL, BIT-1>::highestBit(); } 
};
template<int VAL> class BitWork<VAL, 0> { 
	public: 
		static int highestBit() __attribute__((always_inline)) { return 0; } 
};

#define MAX(A, B) (( (A) > (B) ) ? (A) : (B))

#define USE_CONT 0

// Templated function to translate a clock divider value into the prescalar, scalar, and clock doubling setting for the world.
template <int VAL> void getScalars(uint32_t & preScalar, uint32_t & scalar, uint32_t & dbl) {
    switch(VAL) {
    		// Handle the dbl clock cases
    		case 0: case 1:
            case 2: preScalar = 0; scalar = 0; dbl = 1; break;
            case 3: preScalar = 1; scalar = 0; dbl = 1; break;
            case 5: preScalar = 2; scalar = 0; dbl = 1; break;
            case 7: preScalar = 3; scalar = 0; dbl = 1; break;
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

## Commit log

2014-05-27 Added power supply schematic
    [power.sch]
2014-05-27 Added I2C notes.
2014-05-27 Update i2c_interface.md
    Github is stoopid...
2014-05-27 Update i2c_interface.md
    List nesting...
2020-05-23 Added libraries folder These need to be copied to local Arduino libraries folder. Stupid Arduino.
2020-05-23 Updated 7-segment I2C addresses in doc
2020-05-23 Seven segment display test Use pin A4 for SDA and A5 for SCL
2020-05-23 I2C implemented. THIS IS NOT YET TESTED FULLY.
2020-05-23 Added design files for acrylic box.
    [design-landscape.dwg]
2020-05-23 Added Flappy Bird clone. Added LED setting mode. Changed a few font sizes.
2020-05-23 Added TM logo trace
2020-05-23 Added LEDs test code
2020-05-23 Added to LEDs demo
2020-05-23 Fixed multiple meter ticking delays
    [tick.ino]
2020-05-23 Test functions for complete clock, tidied up libs Includes custom classes SevenSeg, Leds and Voltmeter
2020-05-23 Added libraries to LEDs demo
2020-05-23 Updated schematic to latest version.
    [power.sch]
2020-05-23 Stuff updated. Basic clock functionality added. Header guards added. Ability to enable RTC 1Hz square wave enabled.
    THIS IS ALL UNTESTED. USE THIS AT OWN RISK. THE ARDUINO DOESN'T WORK ON MY COMPUTER.
    [DS1307RTC.cpp, Leds.h, Voltmeter.h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]
2020-05-23 Added LED mode support.
2020-05-23 Allowed enabling and disabling of the RTC interrupt.
2020-05-23 RTC setting implemented. Date functions are not currently used, hence are zero'd for now.
2020-05-23 Done RTC setting better to keep the current date..
2020-05-23 Fixed programmer I2C. Added colour cycle effect.
    [Leds.h, clock.ino, programmer.ino]
2020-05-23 Fixed 59 minutes bug
    [clock.ino]
2020-05-23 Errr. Arduino IDE added a newline to the end of every file. lol. Also added Leds::ledcoord
2020-05-23 Made LED array public. Need it for animations.
2020-05-23 Added initial work for animations framework. (Still untested)
2020-05-23 Remove unneccesary OO from animations. Simpler framework.
2020-05-23 Fix animation_tick. Add test_animation
    [animations.cpp]
2020-05-23 Fixed animations. Changed startup temporarily.≈
    [animations.cpp, clock.ino]
2020-05-23 Made LED mode save to EEPROM (untested)
2020-05-23 Fixed LED mode bug?
    [Leds.h, clock.ino]
2020-05-23 Partial revert of previous commit
    `getLedMode` accepts a `uint8_t&` parameter, which is a reference to a `uint8_t`. For this reason, you just pass in the variable, not a pointer to the variable. This is different to the `getTime` call because the signature of `getTime` changed from `getTime(uint8_t&, uint8_t&, uint8_t&)` to `getTime(uint8_t*, uint8_t*, uint8_t*)` when debugging, and was never changed back to the reference form.
    [clock.ino]
2020-05-23 Jamie broke the build. I fixed.
    [clock.ino]
2020-05-23 Move animation tick framework from loop() to be ready to be called from an interrupt handler. Move colour and pulse led modes to be just animations like everything else. Add ability for rtcTick() to 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
2020-05-23 Changed timer to use timer2 and changed some pins Fixes interference with PWM
    [clock.h, clock.ino, tick.ino]
2020-05-23 Added timerone library and activated animation timer
2020-05-23 Added scales photoshop file. Fixed some animations.
    [animations.cpp]
2020-05-23 Fixed LEDs on boot for modes 2 and 4 (closes #3)
    [Leds.h, clock.ino]
2020-05-23 Fixed rainbow animation cycling (closes #2) Turns out it was cycling, just reaaaaaaaally slowly
    [animations.cpp]
2020-05-23 Added calibration sketch Uses serial port to manually set the value of each meter for testing
2020-05-23 Voltmeter scale calibration (closes #1) Includes Numbers spreadsheet for mins/secs calibration
2020-05-23 Changed Voltmeter to use uint8_t for positions
2020-05-23 Added Voltmeter movement to crazy animation
2020-05-23 Added possible delay to animation start Useful to stop animation interfering with seconds hand damping
    [animations.cpp, clock.ino]
2020-05-23 Added Neutrino mode I2C status into programmer
2020-05-23 Essential neutrino charging at least every 96 hours (closes #8)
